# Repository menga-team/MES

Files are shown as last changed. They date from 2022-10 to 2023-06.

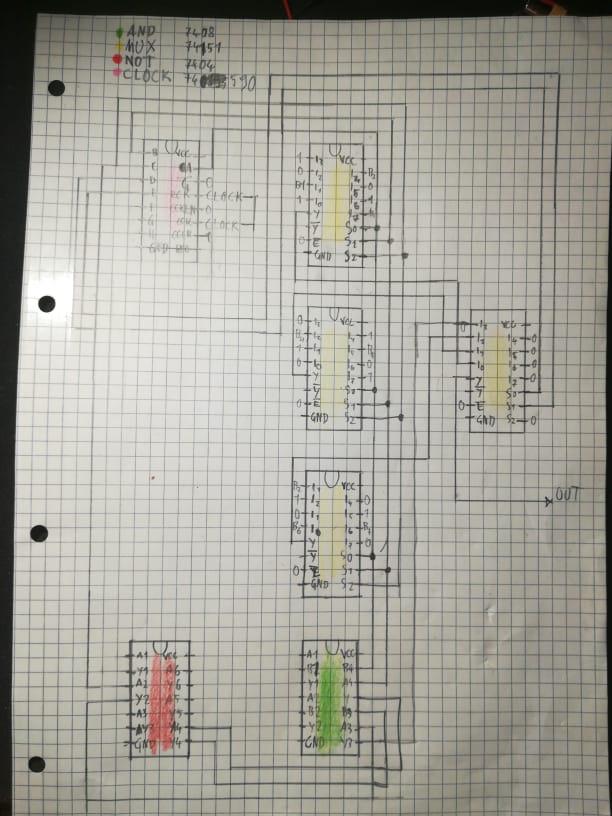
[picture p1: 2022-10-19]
controller/schematic.jpeg

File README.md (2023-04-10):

# Menga Entertainment System

MES is a cartridge-based video game console. For a tutorial and
documentation see our [wiki](https://github.com/menga-team/MES/wiki)

## Installation

### Clone the repository with submodules:

```shell
# via SSH
$ git clone --recursive git@github.com:menga-team/MES.git
# via HTTPS
$ git clone --recursive https://github.com/menga-team/MES.git
```

If you already cloned the repository you can initialize the submodules
with following command:`git submodule update --init`

### Make libopencm3

```shell
    $ cd libopencm3
    $ make
```

## Hacking

Thank you for considering to contribute to MES!
Here are some things before you can get started:

### Style

This repository contains a `.clang-format` file. Please format your
patches with this style guide in mind.

### Revisions

Every CPU firmware has a revision number which is incremented on every
change that concerns the firmware.  This revision number can be then
used in games (e.g. For checking if the game is compatible because
of a bug or API change).

Because its easy to forget incrementing it, we provide a git hook that
will do it for you.  To install it simply run:

```shell
$ cp hooks/post-commit .git/hooks/post-commit
$ chmod +x .git/hooks/post-commit
```

## License

```
MES
Copyright (c) 2022, 2023 menga-team

TinyMT
Copyright (c) 2011, 2013 Mutsuo Saito, Makoto Matsumoto,
Hiroshima University and The University of Tokyo.

udynlink
Copyright (c) 2016 Bogdan Marinescu
Copyright (c) 2022, 2023 menga-team

This program is free software; you can redistribute it and/or modify
it under the terms of the GNU General Public License as published by
the Free Software Foundation; either version 3 of the License, or
(at your option) any later version.

This program is distributed in the hope that it will be useful,
but WITHOUT ANY WARRANTY; without even the implied warranty of
MERCHANTABILITY or FITNESS FOR A PARTICULAR PURPOSE.  See the
GNU General Public License for more details.

You should have received a copy of the GNU General Public License
along with this program; if not, write to the Free Software
Foundation, Inc., 59 Temple Place, Suite 330, Boston, MA  02111-1307  USA
```

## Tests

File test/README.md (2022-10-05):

# MES Tests

To run any test, perform the following commands:
```
cd <test-name>
make clean && make flash
```

## Inbuilt-LED:
The inbuilt LED blinks. Used to test basic funcionality of controller and compilation pipeline.

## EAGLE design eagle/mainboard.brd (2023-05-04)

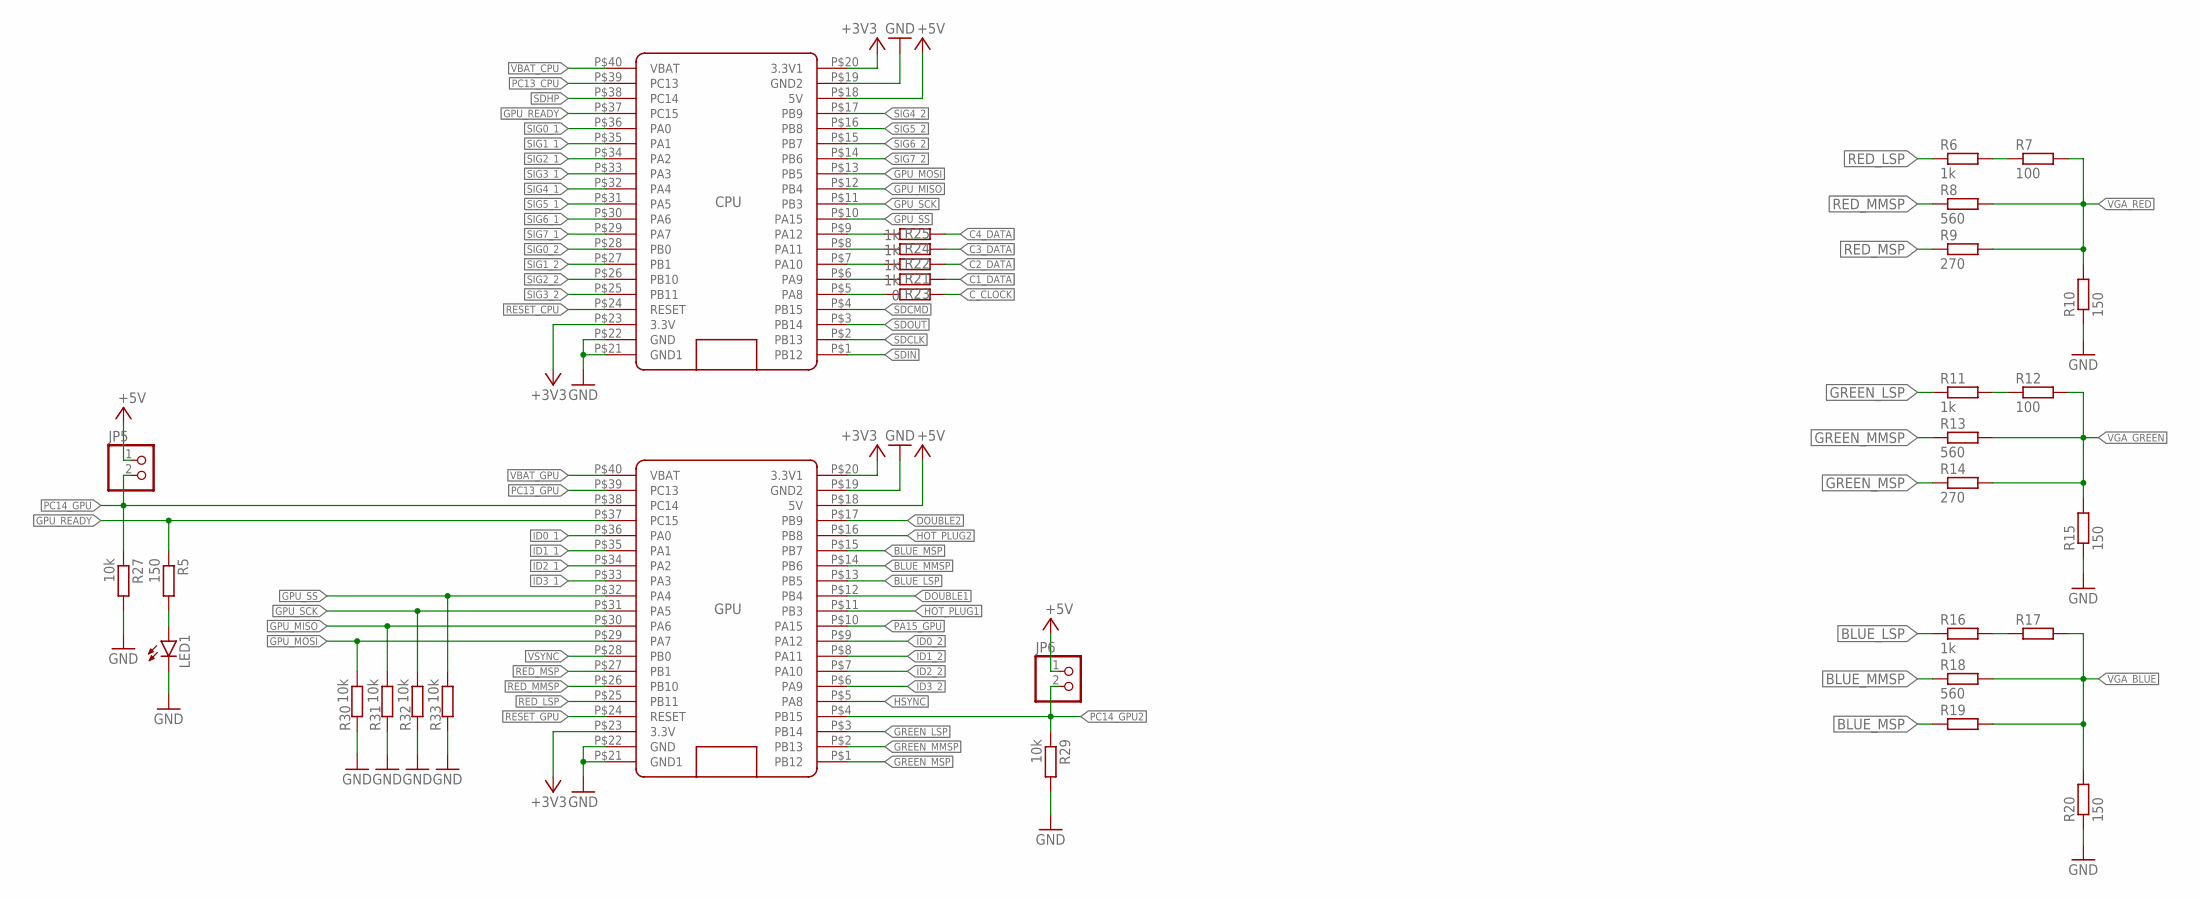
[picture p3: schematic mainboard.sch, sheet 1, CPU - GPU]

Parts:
CPU: BLUE_PILLADVANCED; BLUE_PILL_ADV
GPU: BLUE_PILLADVANCED; BLUE_PILL_ADV
JP5, JP6: PINHD-1X2; 1X02
LED1: LEDCHIPLED_0805; CHIPLED_0805
R5, R10, R15, R20: 150; R0805
R6, R11, R16, R21, R22, R24, R25: 1k; R0805
R7, R12, R17: 100; R0805
R8, R13, R18: 560; R0805
R9, R14, R19: 270; R0805
R23: 0; R0805
R27, R29, R30, R31, R32, R33: 10k; R0805

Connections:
+3V3: CPU.P$20 (3.3V1), CPU.P$23 (3.3V), GPU.P$20 (3.3V1), GPU.P$23 (3.3V); also elsewhere on the board
+5V: CPU.P$18 (5V), GPU.P$18 (5V), JP5.1, JP6.1; also elsewhere on the board
BLUE_LSP: GPU.P$13 (PB5), R16.1
BLUE_MMSP: GPU.P$14 (PB6), R18.1
BLUE_MSP: GPU.P$15 (PB7), R19.1
C1_DATA: R21.1; also elsewhere on the board
C2_DATA: R22.1; also elsewhere on the board
C3_DATA: R24.1; also elsewhere on the board
C4_DATA: R25.1; also elsewhere on the board
C_CLOCK: R23.1; also elsewhere on the board
DOUBLE1: GPU.P$12 (PB4); also elsewhere on the board
DOUBLE2: GPU.P$17 (PB9); also elsewhere on the board
GND: CPU.P$19 (GND2), CPU.P$21 (GND1), CPU.P$22 (GND), GPU.P$19 (GND2), GPU.P$21 (GND1), GPU.P$22 (GND), LED1.C, R10.1, R15.1, R20.1, R27.2, R29.2, R30.2, R31.2, R32.2, R33.2; also elsewhere on the board
GPU_MISO: CPU.P$12 (PB4), GPU.P$30 (PA6), R31.1
GPU_MOSI: CPU.P$13 (PB5), GPU.P$29 (PA7), R30.1
GPU_READY: CPU.P$37 (PC15), GPU.P$37 (PC15), R5.1
GPU_SCK: CPU.P$11 (PB3), GPU.P$31 (PA5), R32.1
GPU_SS: CPU.P$10 (PA15), GPU.P$32 (PA4), R33.1
GREEN_LSP: GPU.P$3 (PB14), R11.1
GREEN_MMSP: GPU.P$2 (PB13), R13.1
GREEN_MSP: GPU.P$1 (PB12), R14.1
HOT_PLUG1: GPU.P$11 (PB3); also elsewhere on the board
HOT_PLUG2: GPU.P$16 (PB8); also elsewhere on the board
HSYNC: GPU.P$5 (PA8); also elsewhere on the board
ID0_1: GPU.P$36 (PA0); also elsewhere on the board
ID0_2: GPU.P$9 (PA12); also elsewhere on the board
ID1_1: GPU.P$35 (PA1); also elsewhere on the board
ID1_2: GPU.P$8 (PA11); also elsewhere on the board
ID2_1: GPU.P$34 (PA2); also elsewhere on the board
ID2_2: GPU.P$7 (PA10); also elsewhere on the board
ID3_1: GPU.P$33 (PA3); also elsewhere on the board
ID3_2: GPU.P$6 (PA9); also elsewhere on the board
unnamed: LED1.A, R5.2
unnamed: R6.2, R7.1
unnamed: R11.2, R12.1
unnamed: R16.2, R17.1
PA8_CPU: CPU.P$5 (PA8), R23.2
PA9_CPU: CPU.P$6 (PA9), R21.2
PA9_CPU1: CPU.P$8 (PA11), R24.2
PA10_CPU: CPU.P$7 (PA10), R22.2
PA10_CPU1: CPU.P$9 (PA12), R25.2
PA15_GPU: GPU.P$10 (PA15)
PC13_CPU: CPU.P$39 (PC13)
PC13_GPU: GPU.P$39 (PC13)
PC14_GPU: GPU.P$38 (PC14), JP5.2, R27.1
PC14_GPU2: GPU.P$4 (PB15), JP6.2, R29.1
RED_LSP: GPU.P$25 (PB11), R6.1
RED_MMSP: GPU.P$26 (PB10), R8.1
RED_MSP: GPU.P$27 (PB1), R9.1
RESET_CPU: CPU.P$24 (RESET)
RESET_GPU: GPU.P$24 (RESET)
SDCLK: CPU.P$2 (PB13); also elsewhere on the board
SDCMD: CPU.P$4 (PB15); also elsewhere on the board
SDHP: CPU.P$38 (PC14); also elsewhere on the board
SDIN: CPU.P$1 (PB12); also elsewhere on the board
SDOUT: CPU.P$3 (PB14); also elsewhere on the board
SIG0_1: CPU.P$36 (PA0); also elsewhere on the board
SIG0_2: CPU.P$28 (PB0); also elsewhere on the board
SIG1_1: CPU.P$35 (PA1); also elsewhere on the board
SIG1_2: CPU.P$27 (PB1); also elsewhere on the board
SIG2_1: CPU.P$34 (PA2); also elsewhere on the board
SIG2_2: CPU.P$26 (PB10); also elsewhere on the board
SIG3_1: CPU.P$33 (PA3); also elsewhere on the board
SIG3_2: CPU.P$25 (PB11); also elsewhere on the board
SIG4_1: CPU.P$32 (PA4); also elsewhere on the board
SIG4_2: CPU.P$17 (PB9); also elsewhere on the board
SIG5_1: CPU.P$31 (PA5); also elsewhere on the board
SIG5_2: CPU.P$16 (PB8); also elsewhere on the board
SIG6_1: CPU.P$30 (PA6); also elsewhere on the board
SIG6_2: CPU.P$15 (PB7); also elsewhere on the board
SIG7_1: CPU.P$29 (PA7); also elsewhere on the board
SIG7_2: CPU.P$14 (PB6); also elsewhere on the board
VBAT_CPU: CPU.P$40 (VBAT)
VBAT_GPU: GPU.P$40 (VBAT)
VGA_BLUE: R17.2, R18.2, R19.2, R20.2; also elsewhere on the board
VGA_GREEN: R12.2, R13.2, R14.2, R15.2; also elsewhere on the board
VGA_RED: R7.2, R8.2, R9.2, R10.2; also elsewhere on the board
VSYNC: GPU.P$28 (PB0); also elsewhere on the board

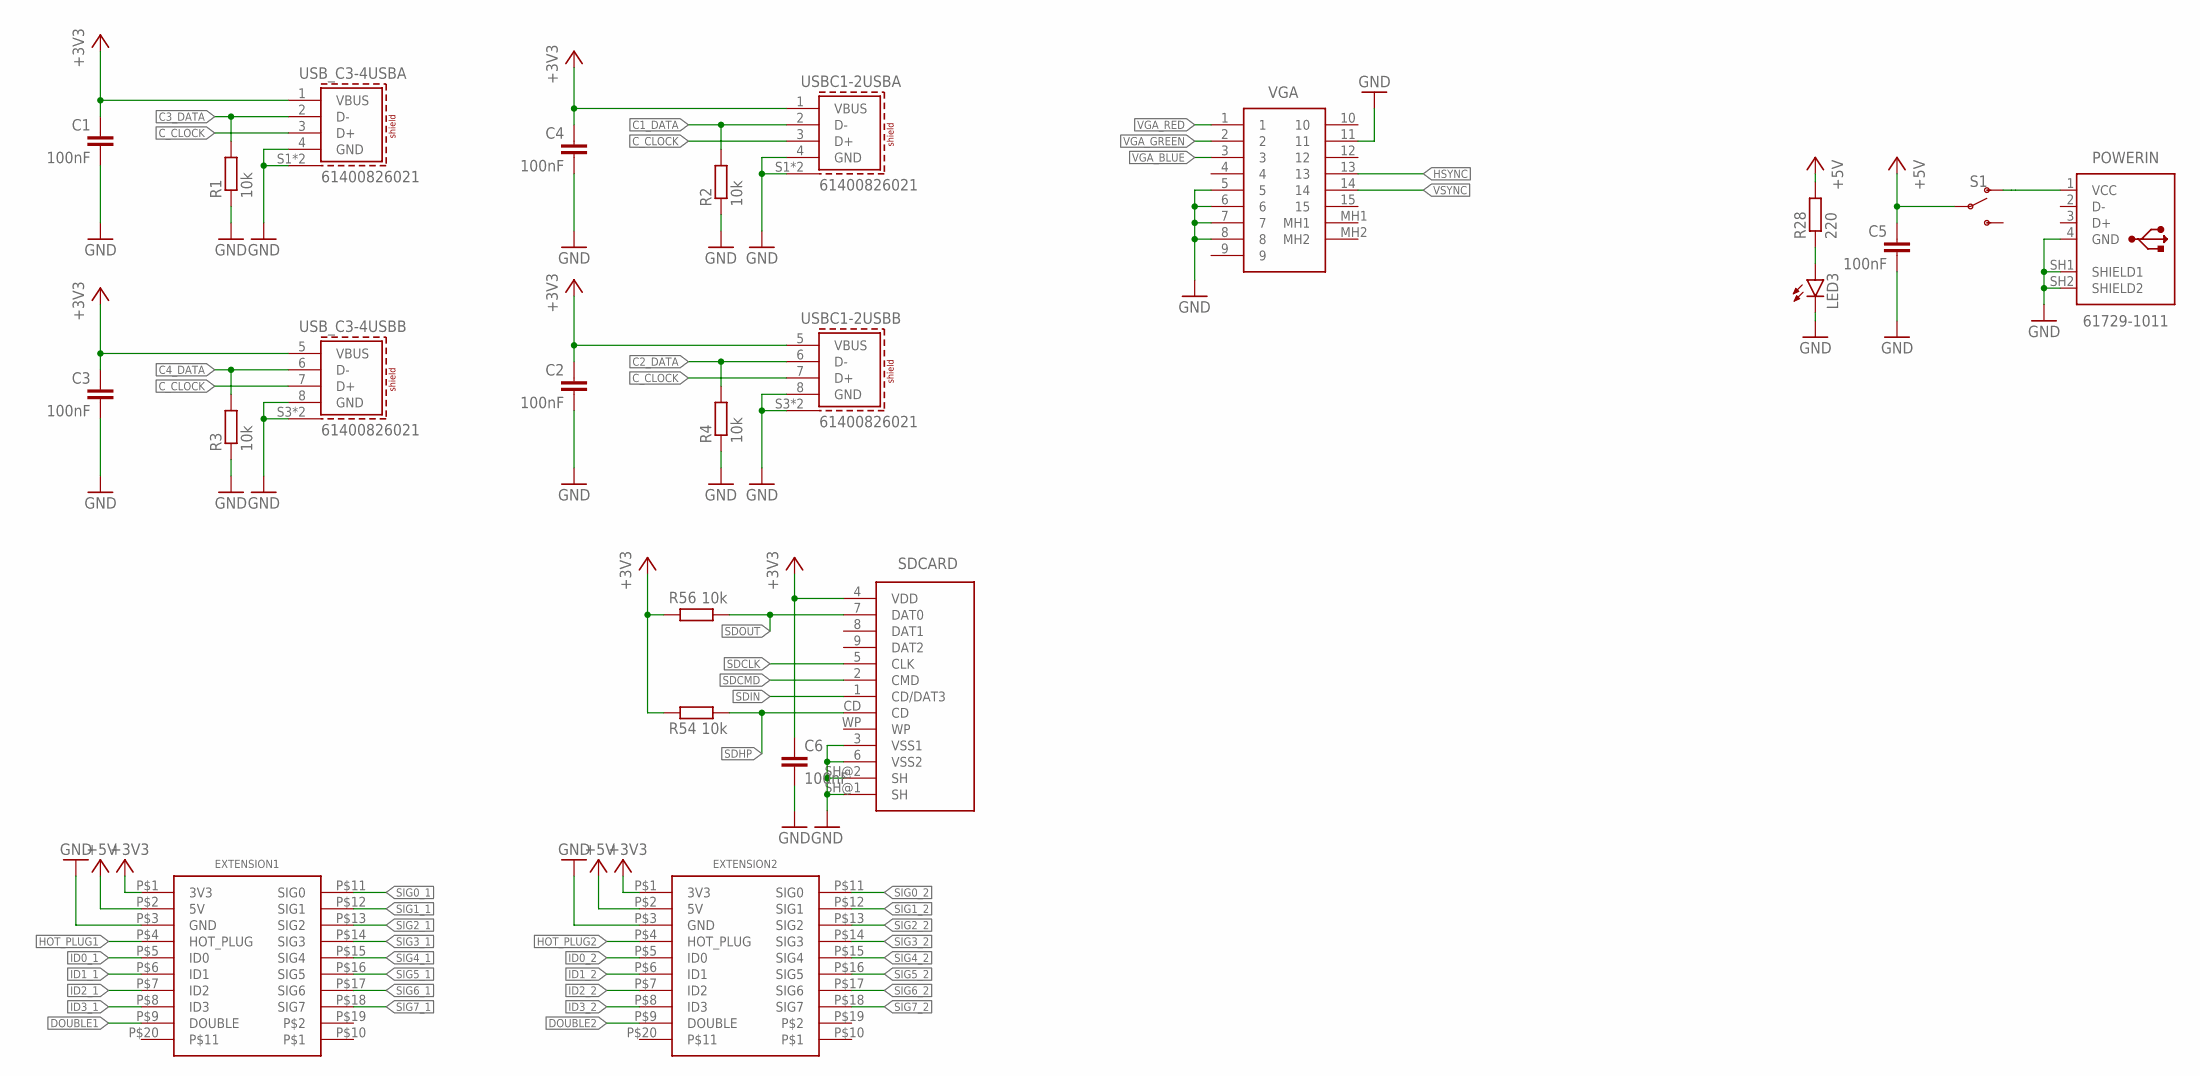
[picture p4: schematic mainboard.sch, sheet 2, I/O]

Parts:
C1, C2, C3, C4, C5, C6: 100nF; C0805
EXTENSION1, EXTENSION2: 3511220BMSS0BNA1_2.54MM_2X20_MALE
LED3: LEDCHIPLED_0805; CHIPLED_0805
POWERIN: 61729-1011; 61729-1011BLF
R1, R2, R3, R4, R54, R56: 10k; R0805
R28: 220; R0805
S1: SWITCH-SPDT-PTH-11.6X4.0MM; SWITCH_SPDT_PTH_11.6X4.0MM
SD-CARD: SD_CARD_SOCKET; SD
USBC1-2: 61400826021
USB_C3-4: 61400826021
VGA: L77HDE15SD1CH4RHNVGA

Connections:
+3V3: C1.1, C2.1, C3.1, C4.1, C6.1, EXTENSION1.P$1 (3V3), EXTENSION2.P$1 (3V3), R54.2, R56.2, SD-CARD.4 (VDD), USBC1-2.1 (VBUS), USBC1-2.5 (VBUS), USB_C3-4.1 (VBUS), USB_C3-4.5 (VBUS); also elsewhere on the board
+5V: C5.1, EXTENSION1.P$2 (5V), EXTENSION2.P$2 (5V), R28.2, S1.2; also elsewhere on the board
C1_DATA: R2.2, USBC1-2.2 (D-); also elsewhere on the board
C2_DATA: R4.2, USBC1-2.6 (D-); also elsewhere on the board
C3_DATA: R1.2, USB_C3-4.2 (D-); also elsewhere on the board
C4_DATA: R3.2, USB_C3-4.6 (D-); also elsewhere on the board
C_CLOCK: USBC1-2.3 (D+), USBC1-2.7 (D+), USB_C3-4.3 (D+), USB_C3-4.7 (D+); also elsewhere on the board
DOUBLE1: EXTENSION1.P$9 (DOUBLE); also elsewhere on the board
DOUBLE2: EXTENSION2.P$9 (DOUBLE); also elsewhere on the board
GND: C1.2, C2.2, C3.2, C4.2, C5.2, C6.2, EXTENSION1.P$3 (GND), EXTENSION2.P$3 (GND), LED3.C, POWERIN.4 (GND), POWERIN.SH1 (SHIELD1), POWERIN.SH2 (SHIELD2), R1.1, R2.1, R3.1, R4.1, SD-CARD.3 (VSS1), SD-CARD.6 (VSS2), SD-CARD.SH@1 (SH), SD-CARD.SH@2 (SH), USBC1-2.4 (GND), USBC1-2.8 (GND), USBC1-2.S1 (SHIELD), USBC1-2.S2 (SHIELD), USBC1-2.S3 (SHIELD), USBC1-2.S4 (SHIELD), USB_C3-4.4 (GND), USB_C3-4.8 (GND), USB_C3-4.S1 (SHIELD), USB_C3-4.S2 (SHIELD), USB_C3-4.S3 (SHIELD), USB_C3-4.S4 (SHIELD), VGA.5, VGA.6, VGA.7, VGA.8, VGA.11; also elsewhere on the board
HOT_PLUG1: EXTENSION1.P$4 (HOT_PLUG); also elsewhere on the board
HOT_PLUG2: EXTENSION2.P$4 (HOT_PLUG); also elsewhere on the board
HSYNC: VGA.13; also elsewhere on the board
ID0_1: EXTENSION1.P$5 (ID0); also elsewhere on the board
ID0_2: EXTENSION2.P$5 (ID0); also elsewhere on the board
ID1_1: EXTENSION1.P$6 (ID1); also elsewhere on the board
ID1_2: EXTENSION2.P$6 (ID1); also elsewhere on the board
ID2_1: EXTENSION1.P$7 (ID2); also elsewhere on the board
ID2_2: EXTENSION2.P$7 (ID2); also elsewhere on the board
ID3_1: EXTENSION1.P$8 (ID3); also elsewhere on the board
ID3_2: EXTENSION2.P$8 (ID3); also elsewhere on the board
unnamed: POWERIN.1 (VCC), S1.1 (O)
unnamed: LED3.A, R28.1
SDCLK: SD-CARD.5 (CLK); also elsewhere on the board
SDCMD: SD-CARD.2 (CMD); also elsewhere on the board
SDHP: R54.1, SD-CARD.CD; also elsewhere on the board
SDIN: SD-CARD.1 (CD/DAT3); also elsewhere on the board
SDOUT: R56.1, SD-CARD.7 (DAT0); also elsewhere on the board
SIG0_1: EXTENSION1.P$11 (SIG0); also elsewhere on the board
SIG0_2: EXTENSION2.P$11 (SIG0); also elsewhere on the board
SIG1_1: EXTENSION1.P$12 (SIG1); also elsewhere on the board
SIG1_2: EXTENSION2.P$12 (SIG1); also elsewhere on the board
SIG2_1: EXTENSION1.P$13 (SIG2); also elsewhere on the board
SIG2_2: EXTENSION2.P$13 (SIG2); also elsewhere on the board
SIG3_1: EXTENSION1.P$14 (SIG3); also elsewhere on the board
SIG3_2: EXTENSION2.P$14 (SIG3); also elsewhere on the board
SIG4_1: EXTENSION1.P$15 (SIG4); also elsewhere on the board
SIG4_2: EXTENSION2.P$15 (SIG4); also elsewhere on the board
SIG5_1: EXTENSION1.P$16 (SIG5); also elsewhere on the board
SIG5_2: EXTENSION2.P$16 (SIG5); also elsewhere on the board
SIG6_1: EXTENSION1.P$17 (SIG6); also elsewhere on the board
SIG6_2: EXTENSION2.P$17 (SIG6); also elsewhere on the board
SIG7_1: EXTENSION1.P$18 (SIG7); also elsewhere on the board
SIG7_2: EXTENSION2.P$18 (SIG7); also elsewhere on the board
VGA_BLUE: VGA.3; also elsewhere on the board
VGA_GREEN: VGA.2; also elsewhere on the board
VGA_RED: VGA.1; also elsewhere on the board
VSYNC: VGA.14; also elsewhere on the board

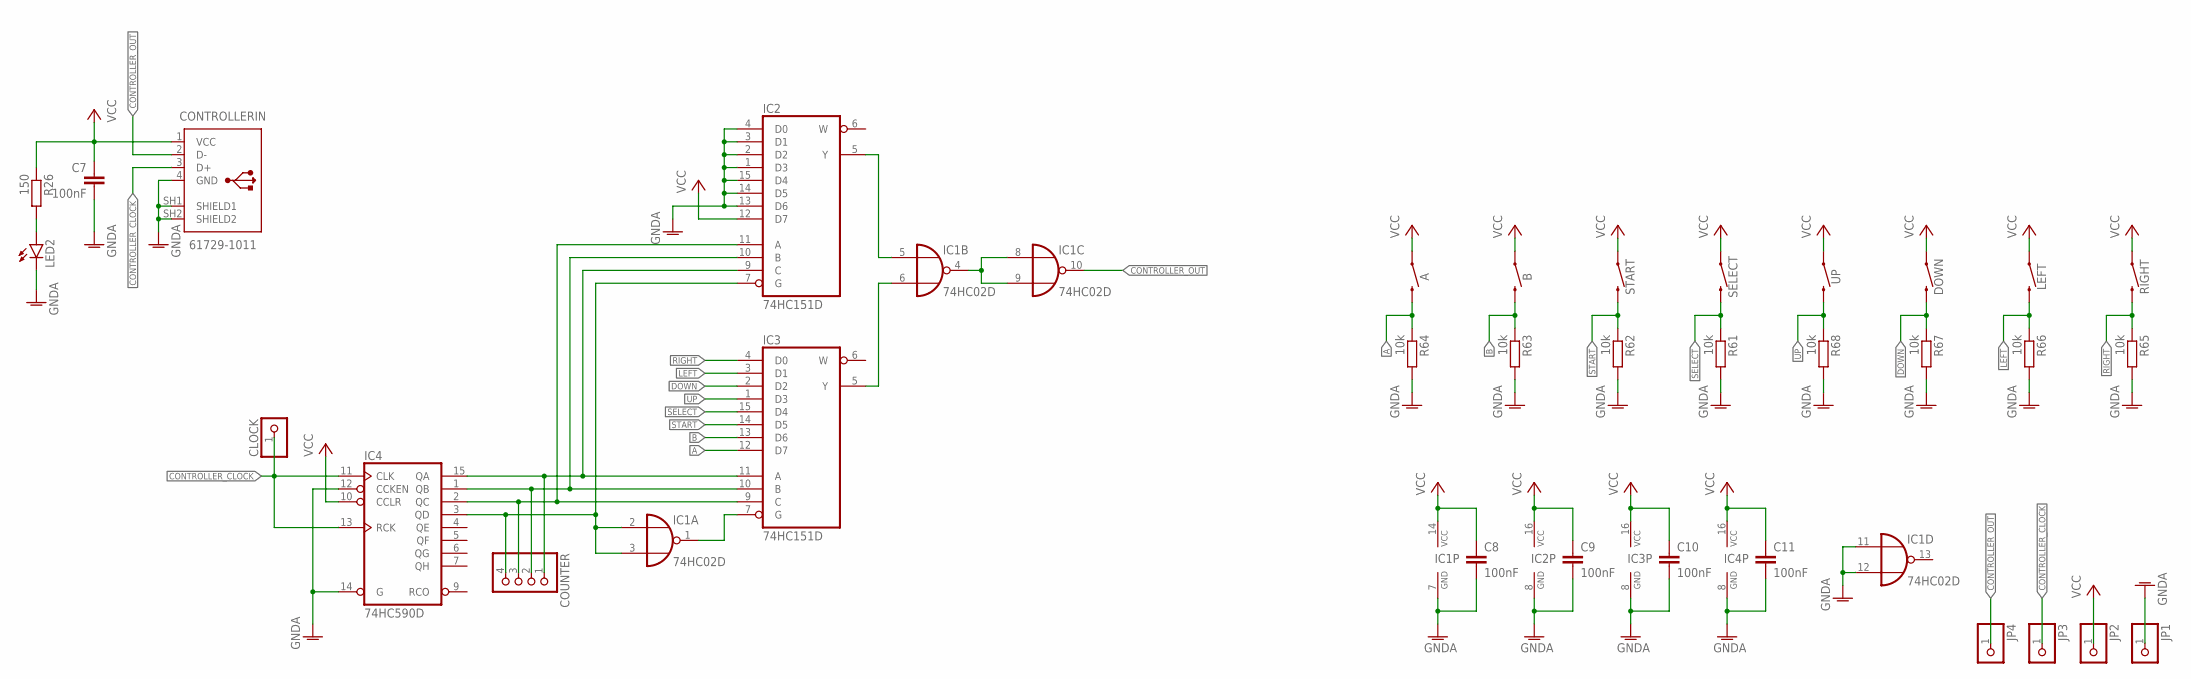
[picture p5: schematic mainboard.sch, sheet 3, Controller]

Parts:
A: MOMENTARY-SWITCH-SPST-PTH-12MM; TACTILE_SWITCH_PTH_12MM
B: MOMENTARY-SWITCH-SPST-PTH-12MM; TACTILE_SWITCH_PTH_12MM
C7, C8, C9, C10, C11: 100nF; C0805
CLOCK: PINHD-1X1; 1X01
CONTROLLERIN: 61729-1011; 61729-1011BLF
COUNTER: PINHD-1X4; 1X04
DOWN: MOMENTARY-SWITCH-SPST-PTH-12MM; TACTILE_SWITCH_PTH_12MM
IC1: 74HC02D; SO14
IC2, IC3: 74HC151D; SO16
IC4: 74HC590D; SO16
JP1, JP2, JP3, JP4: PINHD-1X1; 1X01
LED2: LEDCHIPLED_0805; CHIPLED_0805
LEFT: MOMENTARY-SWITCH-SPST-PTH-12MM; TACTILE_SWITCH_PTH_12MM
R26: 150; R0805
R61, R62, R63, R64, R65, R66, R67, R68: 10k; R0805
RIGHT: MOMENTARY-SWITCH-SPST-PTH-12MM; TACTILE_SWITCH_PTH_12MM
SELECT: MOMENTARY-SWITCH-SPST-PTH-12MM; TACTILE_SWITCH_PTH_12MM
START: MOMENTARY-SWITCH-SPST-PTH-12MM; TACTILE_SWITCH_PTH_12MM
UP: MOMENTARY-SWITCH-SPST-PTH-12MM; TACTILE_SWITCH_PTH_12MM

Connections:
A: A.3 (2), IC3.12 (D7), R64.1
B: B.3 (2), IC3.13 (D6), R63.1
CONTROLLER_CLOCK: CLOCK.1, CONTROLLERIN.3 (D+), IC4.11 (CLK), IC4.13 (RCK), JP3.1
CONTROLLER_OUT: CONTROLLERIN.2 (D-), IC1.10 (O), JP4.1
DOWN: DOWN.3 (2), IC3.2 (D2), R67.1
GNDA: C7.2, C8.2, C9.2, C10.2, C11.2, CONTROLLERIN.4 (GND), CONTROLLERIN.SH1 (SHIELD1), CONTROLLERIN.SH2 (SHIELD2), IC1.7 (GND), IC1.11 (I0), IC1.12 (I1), IC2.1 (D3), IC2.2 (D2), IC2.3 (D1), IC2.4 (D0), IC2.8 (GND), IC2.13 (D6), IC2.14 (D5), IC2.15 (D4), IC3.8 (GND), IC4.8 (GND), IC4.12 (CCKEN), IC4.14 (G), JP1.1, LED2.C, R61.2, R62.2, R63.2, R64.2, R65.2, R66.2, R67.2, R68.2
LEFT: IC3.3 (D1), LEFT.3 (2), R66.1
unnamed: LED2.A, R26.2
unnamed: IC1.5 (I0), IC2.5 (Y)
unnamed: IC1.6 (I1), IC3.5 (Y)
unnamed: IC1.4 (O), IC1.8 (I0), IC1.9 (I1)
unnamed: COUNTER.1, IC2.9 (C), IC3.11 (A), IC4.15 (QA)
unnamed: COUNTER.2, IC2.10 (B), IC3.10 (B), IC4.1 (QB)
unnamed: COUNTER.3, IC2.11 (A), IC3.9 (C), IC4.2 (QC)
unnamed: COUNTER.4, IC1.2 (I0), IC1.3 (I1), IC2.7 (G), IC4.3 (QD)
unnamed: IC1.1 (O), IC3.7 (G)
RIGHT: IC3.4 (D0), R65.1, RIGHT.3 (2)
SELECT: IC3.15 (D4), R61.1, SELECT.3 (2)
START: IC3.14 (D5), R62.1, START.3 (2)
UP: IC3.1 (D3), R68.1, UP.3 (2)
VCC: A.1, B.1, C7.1, C8.1, C9.1, C10.1, C11.1, CONTROLLERIN.1 (VCC), DOWN.1, IC1.14 (VCC), IC2.12 (D7), IC2.16 (VCC), IC3.16 (VCC), IC4.10 (CCLR), IC4.16 (VCC), JP2.1, LEFT.1, R26.1, RIGHT.1, SELECT.1, START.1, UP.1

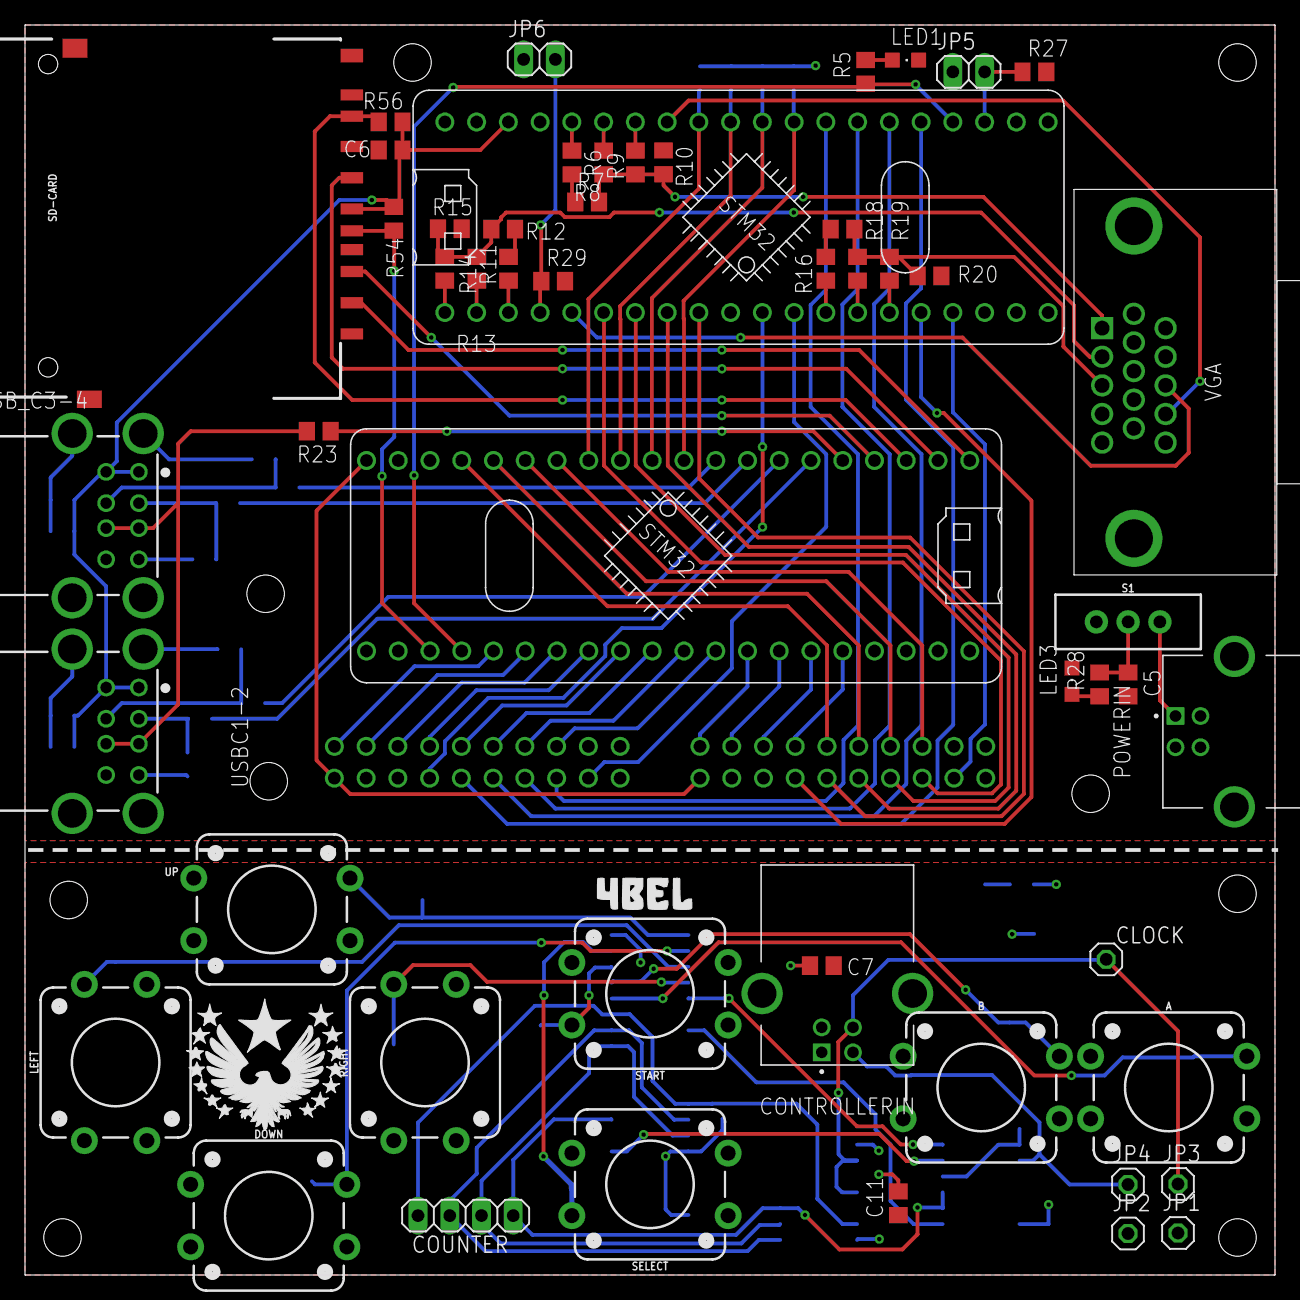
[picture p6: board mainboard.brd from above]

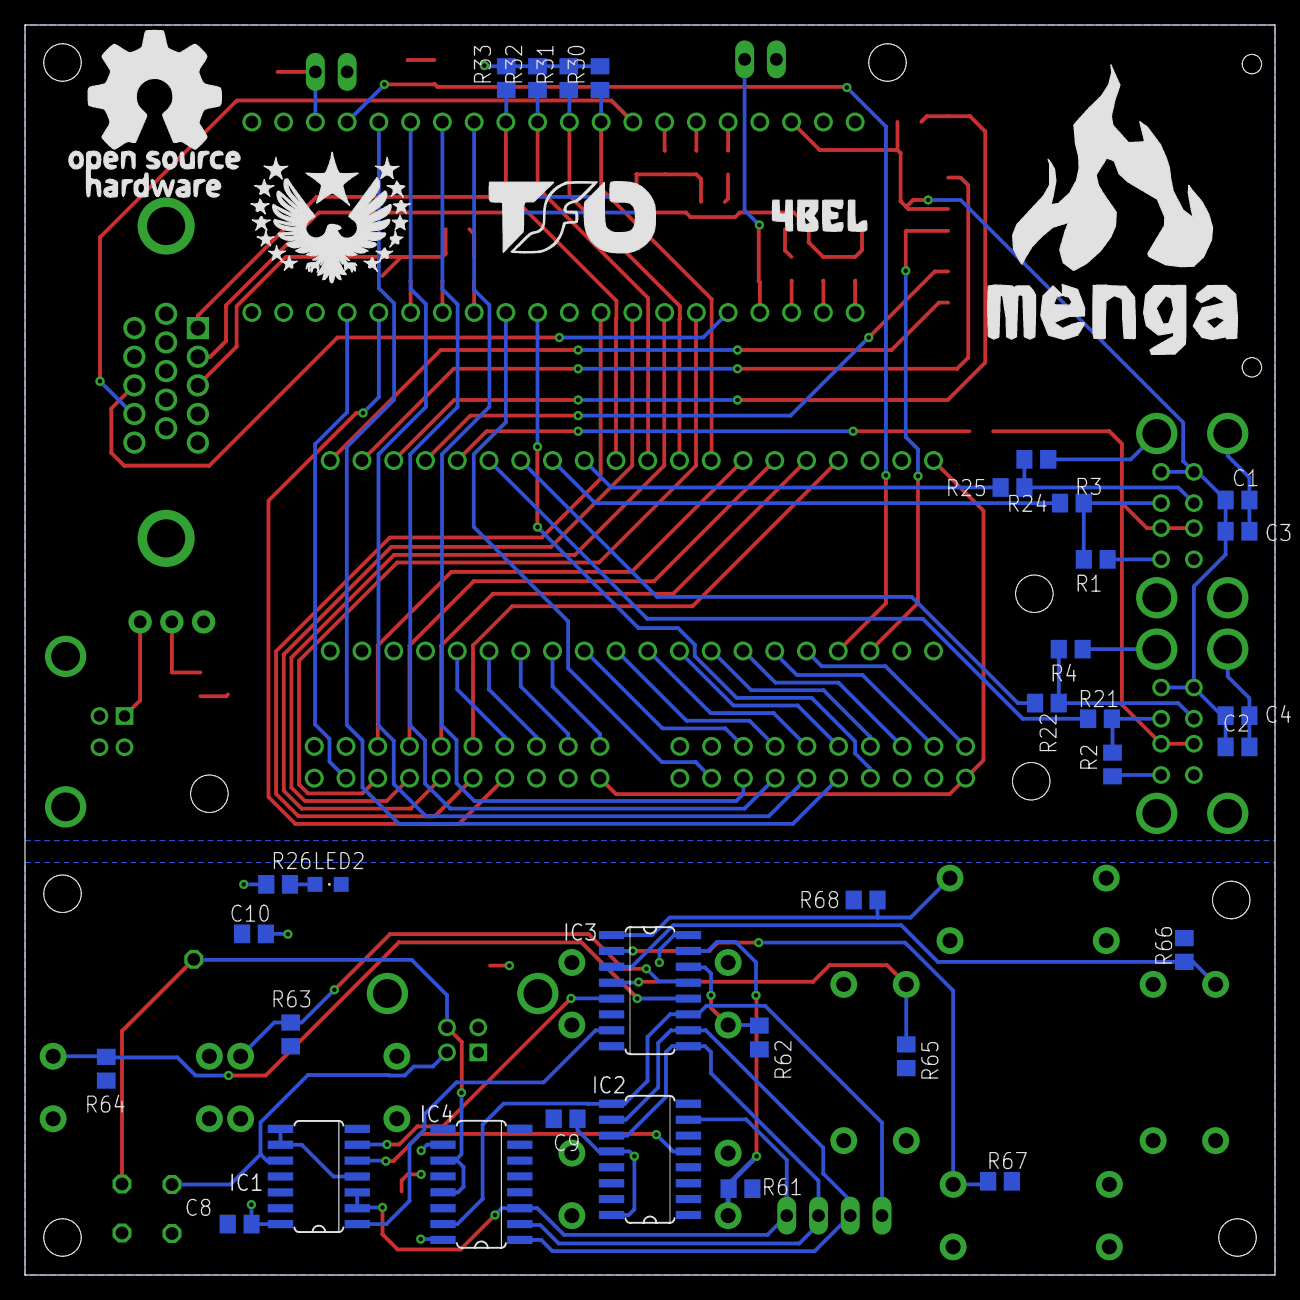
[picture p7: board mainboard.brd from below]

Board: 2 copper layers, 100.0 x 100.0 mm, 88 parts (33 on the bottom side), 94 nets.

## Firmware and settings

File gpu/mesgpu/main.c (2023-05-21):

#include "main.h"
#include "gpu.h"
#include "libopencm3/cm3/systick.h"
#include "mesgraphics.h"
#include <libopencm3/cm3/nvic.h>
#include <libopencm3/stm32/dma.h>
#include <libopencm3/stm32/gpio.h>
#include <libopencm3/stm32/rcc.h>
#include <libopencm3/stm32/spi.h>
#include <libopencm3/stm32/timer.h>
#include <memory.h>
#include <mesmath.h>
#include <stdint.h>
#include <stdio.h>

// Include error screen as 'error'
#include "images/error.m3ifc"
// Include cpu timeout screen as 'cpu_timeout'
#include "images/cpu_timeout.m3ifc"
// The boot screen
#include "images/splash_screen.m3ifc"
// The adjust brightness screen
#include "images/adjust_brightness.m3ifc"
// Sdcard icon
#include "images/sdcard.m3ifc"
// Controller icons
#include "images/controller1.m3ifc"
#include "images/controller2.m3ifc"
#include "images/controller3.m3ifc"
#include "images/controller4.m3ifc"

int main(void) {
    rcc_clock_setup_pll(&rcc_hse_configs[RCC_CLOCK_HSE8_72MHZ]);
    setup_output();
    gpu_init();
    setup_video();
    start_communication();
    start_video();
    // Setup timeout
    systick_clear();
    systick_set_clocksource(STK_CSR_CLKSOURCE_AHB_DIV8);
    systick_set_reload(16777215); // 24-bit limit. (~1.8s)
    systick_interrupt_enable();
    systick_counter_enable();
    while (run) {
        // we have ~5µs every line and ~770µs every frame
        handle_operation();
    }

    while (true)
        ;
}

void sys_tick_handler(void) {
    systick_interrupt_disable();
    systick_counter_disable();
    systick_clear();
    // Did we sync after ~1.8s?
    // If we didn't then show the timeout error.
    if (processing_stage == UNINITIALIZED) {
        // Show timeout screen if cpu failed to sync.
        cpu_communication_timeout();
        // Run gets disabled when the 1. operation sent is not the init
        // operation. Inorder to help debugging we will display the
        // "COM_BRK" error, meaning the gpu is able to recieve from the
        // cpu, but the communication might be unreliable.
        if (!run) {
            gpu_write(front_buffer, 118, 112, 2, 3, "COM_BRK");
        }
    }
}

void setup_output(void) {
    rcc_periph_clock_enable(RCC_AFIO);
    rcc_periph_clock_enable(RCC_GPIOA);
    rcc_periph_clock_enable(RCC_GPIOB);
    rcc_periph_clock_enable(RCC_GPIOC);
    gpio_set_mode(GPIOC, GPIO_MODE_OUTPUT_2_MHZ, GPIO_CNF_OUTPUT_PUSHPULL,
                  GPIO13); // built-in
    gpio_set_mode(GPU_READY_PORT, GPIO_MODE_OUTPUT_2_MHZ,
                  GPIO_CNF_OUTPUT_PUSHPULL, GPU_READY);
    gpio_clear(GPU_READY_PORT, GPU_READY); // set gpu ready to low
    gpio_set(GPIOC, GPIO13);
    // A8: hsync (yellow cable)
    // B0: vsync (orange cable)
    gpio_set_mode(GPIOA, GPIO_MODE_OUTPUT_2_MHZ, GPIO_CNF_OUTPUT_ALTFN_PUSHPULL,
                  GPIO_TIM1_CH1); // PA8
    gpio_set_mode(GPIOB, GPIO_MODE_OUTPUT_2_MHZ, GPIO_CNF_OUTPUT_ALTFN_PUSHPULL,
                  GPIO_TIM3_CH3); // PB0
    gpio_set_mode(GPIO_COLOR_PORT, GPIO_MODE_OUTPUT_50_MHZ,
                  GPIO_CNF_OUTPUT_PUSHPULL,
                  RED_MSP | RED_MMSP | RED_LSP | GREEN_MSP | GREEN_MMSP |
                      GREEN_LSP | BLUE_MSP | BLUE_MMSP | BLUE_LSP);
    gpio_clear(GPIO_COLOR_PORT, GPIO_ALL); // reset colors
}

void setup_video(void) { gpu_blank(front_buffer, 0x00); }

void start_communication(void) {
    RCC_APB1ENR &= ~RCC_APB1ENR_I2C1EN; // disable i2c if it happend to be
                                        // enabled, see erata.
    // SS=PA4 SCK=PA5 MISO=PA6 MOSI=PA7
    gpio_set_mode(GPIOA, GPIO_MODE_OUTPUT_50_MHZ,
                  GPIO_CNF_OUTPUT_ALTFN_PUSHPULL, GPIO6);
    gpio_set_mode(GPIOA, GPIO_MODE_INPUT, GPIO_CNF_INPUT_FLOAT,
                  GPIO5 | GPIO4 | GPIO7);
    rcc_periph_clock_enable(RCC_SPI1);
    spi_reset(SPI1);
    spi_set_slave_mode(SPI1);
    spi_set_clock_polarity_0(SPI1);
    spi_set_clock_phase_1(SPI1);
    spi_set_dff_8bit(SPI1);
    spi_send_msb_first(SPI1);
    spi_enable(SPI1);
    rcc_periph_clock_enable(RCC_DMA1);
    nvic_set_priority(NVIC_DMA1_CHANNEL2_IRQ, 1);
    nvic_enable_irq(NVIC_DMA1_CHANNEL2_IRQ);
    dma_channel_reset(DMA1, DMA_CHANNEL2);
    dma_set_peripheral_address(DMA1, DMA_CHANNEL2, (uint32_t)&SPI1_DR);
    dma_set_read_from_peripheral(DMA1, DMA_CHANNEL2);
    dma_enable_memory_increment_mode(DMA1, DMA_CHANNEL2);
    dma_set_peripheral_size(DMA1, DMA_CHANNEL2, DMA_CCR_PSIZE_8BIT);
    dma_set_memory_size(DMA1, DMA_CHANNEL2, DMA_CCR_MSIZE_8BIT);
    dma_set_priority(DMA1, DMA_CHANNEL2, DMA_CCR_PL_VERY_HIGH);
    dma_enable_transfer_complete_interrupt(DMA1, DMA_CHANNEL2);
    spi_enable_rx_dma(SPI1);
    dma_recieve_operation();
    gpu_ready_port = 0;
}

void dma_recieve_operation(void) {
    dma_recieve((uint32_t)&operation, OPERATION_LENGTH);
}

void dma_recieve(uint32_t adr, uint32_t len) {
    dma_set_memory_address(DMA1, DMA_CHANNEL2, adr);
    dma_set_number_of_data(DMA1, DMA_CHANNEL2, len);
    dma_enable_channel(DMA1, DMA_CHANNEL2);
}

void start_video(void) {
    // timers are driven by a 72MHz clock
    // TIM1 -> H-SYNC & scanline interrupt
    rcc_periph_clock_enable(RCC_TIM1);
    rcc_periph_reset_pulse(RST_TIM1);
    timer_enable_break_main_output(TIM1);
    timer_set_mode(TIM1, TIM_CR1_CKD_CK_INT, TIM_CR1_CMS_EDGE, TIM_CR1_DIR_UP);
    // 25175000/4 = 6293750
    // 72000000/6293750 = 11.44 = 11
    timer_set_prescaler(TIM1,
                        uround((double)rcc_apb2_frequency /
                               (double)(PIXEL_CLOCK / BUFFER_TO_VIDEO_RATIO)) -
                            1);
    timer_set_period(TIM1, (H_WHOLE_LINE_PIXELS / BUFFER_TO_VIDEO_RATIO) - 1);
    timer_disable_preload(TIM1);
    timer_continuous_mode(TIM1);
    timer_set_counter(TIM1, 0);
    timer_enable_oc_preload(TIM1, TIM_OC1);
    timer_enable_oc_output(TIM1, TIM_OC1);
    timer_set_oc_mode(TIM1, TIM_OC1, TIM_OCM_PWM1);
    // This OC is responsible for the horizontal sync pulse...
    // We will send the sync pulse at the beging because it is easier.
    // The backporch will follow after it, and the front porch is at the
    // end.
    timer_set_oc_value(TIM1, TIM_OC1,
                       (H_SYNC_PULSE_PIXELS / BUFFER_TO_VIDEO_RATIO) - 1);
#if H_SYNC_POLARITY == 1
    timer_set_oc_polarity_high(TIM1, TIM_OC1);
#else
    timer_set_oc_polarity_low(TIM1, TIM_OC1);
#endif
    nvic_enable_irq(NVIC_TIM1_CC_IRQ);
    nvic_set_priority(NVIC_TIM1_CC_IRQ, 0);
    // OC2 will let us know when we need to start preparing and outputting
    // the image Start a little sooner because we are doing more than just
    // outputting the pixels.
    timer_set_oc_value(
        TIM1, TIM_OC2,
        ((H_SYNC_PULSE_PIXELS + H_BACK_PORCH_PIXELS) / BUFFER_TO_VIDEO_RATIO) -
            9);
    timer_enable_irq(TIM1, TIM_DIER_CC2IE);
    // TIM3 -> V-SYNC & line count
    rcc_periph_clock_enable(RCC_TIM3);
    rcc_periph_reset_pulse(RST_TIM3);
    timer_set_mode(TIM3, TIM_CR1_CKD_CK_INT, TIM_CR1_CMS_EDGE, TIM_CR1_DIR_UP);
    // 25175000/4 = 6293750
    // 6293750/200 = 31468.75
    // 72000000.0/31468.75 = 228.8 = 229
    timer_set_prescaler(
        TIM3, uround((double)rcc_apb2_frequency /
                     (double)((double)(PIXEL_CLOCK / BUFFER_TO_VIDEO_RATIO) /
                              (double)(H_WHOLE_LINE_PIXELS /
                                       BUFFER_TO_VIDEO_RATIO))) -
                  1);
    timer_set_period(TIM3, V_WHOLE_FRAME_LINES - 1);
    timer_disable_preload(TIM3);
    timer_continuous_mode(TIM3);
    timer_set_oc_value(TIM3, TIM_OC3, V_SYNC_PULSE_LINES);
    timer_set_counter(TIM3, 0);
    timer_enable_oc_preload(TIM3, TIM_OC3);
    timer_enable_oc_output(TIM3, TIM_OC3);
    timer_set_oc_mode(TIM3, TIM_OC3, TIM_OCM_PWM1);
#if V_SYNC_POLARITY == 1
    timer_set_oc_polarity_high(TIM3, TIM_OC3);
#else
    timer_set_oc_polarity_low(TIM3, TIM_OC3);
#endif
    // initialize line counters
    buffer_line = 0;
    sub_line = -1;
    // start timers
    timer_enable_counter(TIM3);
    timer_enable_counter(TIM1);
}

void __attribute__((optimize("O3"))) tim1_cc_isr(void) {
    TIM_SR(TIM1) = 0x0000;
    if (TIM3_CNT > V_SYNC_PULSE_LINES + V_BACK_PORCH_LINES - 3 &&
        TIM3_CNT <
            V_SYNC_PULSE_LINES + V_BACK_PORCH_LINES + V_DISPLAY_LINES - 20) {
        // while drawing we don't want to communicate, because DMA and
        // CPU can only access memory one at a time. When we are
        // recieving data and drawing at the same time, artifacts will
        // appear.
        GPIO_BRR(GPU_READY_PORT) = GPU_READY;

        // Increment subline
        sub_line++;

        // Send the scanline
        line = (const void *)front_buffer +
               (buffer_line * (BUFFER_WIDTH / 8) * BUFFER_BPP);

#include "scanline.g.c"

        // Some monitors sample their black voltage level in the back
        // porch, so we need to stop outputting color.
        GPIO_BRR(GPIO_COLOR_PORT) = GPIO_ALL;

        // Branches are last because we don't want variable execution
        // time before sending the pixels.
        if (sub_line == BUFFER_TO_VIDEO_RATIO) {
            buffer_line++;
            sub_line = 0;
        }
        if (buffer_line == BUFFER_HEIGHT)
            buffer_line = 0;
    } else {
        // we don't want to send a possible GPU_READY after finishing a
        // line, because that's just to many interrupts.
        GPIO_ODR(GPU_READY_PORT) = gpu_ready_port;
    }
}

void generic_error(void) {
    run = false;
    gpu_ready_port = 0;
    color_palette[0] = COLOR(0b000, 0b000, 0b111);
    color_palette[1] = COLOR(0b111, 0b111, 0b111);
    memcpy(front_buffer, error, SCREEN_BUFFER_SIZE);
}

void invalid_operation(uint8_t *invalid_op) {
    generic_error();
    gpu_write(front_buffer, 2, 80, 1, 0, "-UNIMPLEMENTED  OPERATION-");
    char *operation_string = malloc(sizeof(char) * 25); // 24chars + NUL
    sprintf(operation_string, "%02x %02x %02x %02x  %02x %02x %02x %02x",
            invalid_op[0], invalid_op[1], invalid_op[2], invalid_op[3],
            invalid_op[4], invalid_op[5], invalid_op[6], invalid_op[7]);
    gpu_write(front_buffer, 8, 96, 1, 0, operation_string);
    free(operation_string);
}

void unexpected_data(enum Stage c_stage) {
    generic_error();
    gpu_write(front_buffer, 2, 80, 1, 0, "  -  UNEXPECTED  DATA  -  ");
    gpu_write(front_buffer, 0, 88, 1, 0, "Current processing stage:");
    char *buf = malloc(sizeof(char) * 27); // 26chars (whole line) + NUL
    sprintf(buf, "%s (%02x)", stage_pretty_names[c_stage], c_stage);
    gpu_write(front_buffer, 0, 96, 1, 0, buf);
    sprintf(buf, "Recieved data: (%04lx)", DMA_CMAR(DMA1, DMA_CHANNEL2));
    gpu_write(front_buffer, 0, 104, 1, 0, buf);
    uint8_t *data = (uint8_t *)DMA_CMAR(DMA1, DMA_CHANNEL2);
    sprintf(buf, "%02x%02x%02x%02x%02x%02x%02x%02x%02x%02x%02x ...", data[0],
            data[1], data[2], data[3], data[4], data[5], data[6], data[7],
            data[8], data[9], data[10]);
    gpu_write(front_buffer, 0, 112, 1, 0, buf);
    free(buf);
}

void too_large_data(uint16_t bytes) {
    generic_error();
    gpu_write(front_buffer, 2, 80, 1, 0, "-OPERATION DATA TOO LARGE-");
    char *buf = malloc(sizeof(char) * 27); // 26chars (whole line) + NUL
    sprintf(buf, "%u > %u!", bytes, OPERATION_DATA_LENGTH);
    gpu_write(front_buffer, 2, 88, 1, 0, buf);
    gpu_write(front_buffer, 2, 96, 1, 0, "OPERATION:");
    sprintf(buf, "%02x %02x %02x %02x  %02x %02x %02x %02x", operation[0],
            operation[1], operation[2], operation[3], operation[4],
            operation[5], operation[6], operation[7]);
    gpu_write(front_buffer, 2, 104, 1, 0, buf);
    free(buf);
}

void cpu_communication_timeout(void) {
    // FIXME: When a timeout is displayed the lines are in the wrong order.
    //      This is probably because the pixels get copied in a interrupt.
    //      A solution could be to copy the pixels via DMA or to copy the
    //      pixels outside of the interrupt.
    color_palette[0] = COLOR(0b000, 0b000, 0b000);
    color_palette[1] = COLOR(0b110, 0b110, 0b110);
    color_palette[2] = COLOR(0b100, 0b100, 0b100);
    color_palette[3] = COLOR(0b111, 0b111, 0b111);
    memcpy(front_buffer, cpu_timeout, SCREEN_BUFFER_SIZE);
}

void dma1_channel2_isr(void) {
    dma_clear_interrupt_flags(DMA1, DMA_CHANNEL2, DMA_ISR_TCIF_BIT);
    dma_disable_channel(DMA1, DMA_CHANNEL2);
    switch (processing_stage) {
    case UNINITIALIZED:
        if (OPERATION_ID(operation) != OPERATION_ID_INIT) {
            // 1. Operation was not the sync operation...
            // The communication is not reliable and should not be
            // trusted with further operations. An error will be
            // displayed automatically via the systick interupt.
            run = false;
            break;
        }
    case READY:
        processing_stage = UNHANDELED_OPERATION;
        break;
    case WAITING_FOR_DATA:
        processing_stage = UNHANDELED_DATA;
        break;
    case WAITING_FOR_DMA:
        processing_stage = READY;
        dma_recieve_operation();
        GPIO_BSRR(GPU_READY_PORT) = GPU_READY;
        gpu_ready_port = GPU_READY;
        break;
    default:
        unexpected_data(processing_stage);
        break;
    }
}

void handle_operation(void) {
    switch (processing_stage) {
    case UNHANDELED_OPERATION:
        new_operation();
        break;
    case UNHANDELED_DATA:
        new_data();
        break;
    default:
        break;
    }
}

void new_operation(void) {
    gpu_ready_port = 0;
    GPIO_BRR(GPU_READY_PORT) = GPU_READY;
    if (INTERNAL_OPERATION(operation)) {

        switch (OPERATION_ID(operation)) {
        case INTERNAL_SHOW_STARTUP:
            memcpy(front_buffer, splash_screen, SCREEN_BUFFER_SIZE);
            uint8_t su_colors[4][3] = {
                {0b000, 0b000, 0b000},
                {0b111, 0b001, 0b001},
                {0b101, 0b101, 0b101},
                {0b111, 0b111, 0b111},
            };

            // set the inital palette
            for (uint8_t i = 0; i < 4; ++i)
                color_palette[i] =
                    COLOR(su_colors[i][0], su_colors[i][1], su_colors[i][2]);

            gpu_write(front_buffer, 15, 100, 0, 3, "GITHUB.COM/MENGA-TEAM");
            // not going to start a timer just for that...
            for (uint32_t i = 0; i < 5000000; ++i)
                __asm__("nop");

            // fade out
            while (su_colors[3][0] != 0) { // [3] is white
                for (uint8_t i = 0; i < 4; ++i) {
                    for (uint8_t j = 0; j < 3; ++j) {
                        if (su_colors[i][j] != 0)
                            su_colors[i][j]--;
                    }
                    color_palette[i] = COLOR(su_colors[i][0], su_colors[i][1],
                                             su_colors[i][2]);
                }
                for (uint32_t i = 0; i < 200000; ++i)
                    __asm__("nop");
            }
            gpu_blank(front_buffer, 0x00);
            gpu_reset_palette();
            break;
        case INTERNAL_ADJUST_BRIGHTNESS:
            memcpy(front_buffer, adjust_brightness, SCREEN_BUFFER_SIZE);
            uint8_t ab_colors[8][3] = {
                {0b000, 0b000, 0b000}, {0b110, 0b110, 0b110},
                {0b101, 0b101, 0b101}, {0b111, 0b111, 0b111},
                {0b100, 0b100, 0b100}, {0b011, 0b011, 0b011},
                {0b010, 0b010, 0b010}, {0b001, 0b001, 0b001},
            };

            // set the inital palette
            for (uint8_t i = 0; i < 8; ++i)
                color_palette[i] =
                    COLOR(ab_colors[i][0], ab_colors[i][1], ab_colors[i][2]);

            gpu_write(front_buffer, 10, 42, 3, 0, " PLEASE ADJUST YOUR     ");
            gpu_write(front_buffer, 10, 50, 3, 0, " MONITOR OR TELEVISION  ");
            gpu_write(front_buffer, 10, 58, 3, 0, " BRIGHTNESS SETTINGS    ");
            gpu_write(front_buffer, 10, 66, 3, 0, " IF YOU CAN'T SEE       ");
            gpu_write(front_buffer, 10, 74, 3, 0, " 7 DISTINCT SQUARES     ");

            gpu_write(front_buffer, 10, 90, 3, 0, " PLEASE PLAY IN A       ");
            gpu_write(front_buffer, 10, 98, 3, 0, " WELL-LIT AREA          ");
            gpu_write(front_buffer, 10, 106, 3, 0, " FROM A SAFE DISTANCE   ");

            for (uint32_t i = 0; i < 15000000; ++i)
                __asm__("nop");

            // fade out
            while (ab_colors[3][0] != 0) { // [3] is white
                for (uint8_t i = 0; i < 8; ++i) {
                    for (uint8_t j = 0; j < 3; ++j) {
                        if (ab_colors[i][j] != 0)
                            ab_colors[i][j]--;
                    }
                    color_palette[i] = COLOR(ab_colors[i][0], ab_colors[i][1],
                                             ab_colors[i][2]);
                }
                for (uint32_t i = 0; i < 300000; ++i)
                    __asm__("nop");
            }
            gpu_blank(front_buffer, 0x00);
            gpu_reset_palette();
            break;
        case INTERNAL_DRAW_SDCARD:
            gpu_insert_buf(OPERATION_BUFFER(operation), sdcard, SDCARD_WIDTH,
                           SDCARD_HEIGHT, operation[6], operation[7]);
            break;
        case INTERNAL_DRAW_CONTROLLER: {
            const uint8_t *texture;
            switch (operation[4]) {
            case 0:
                texture = controller1;
                break;
            case 1:
                texture = controller2;
                break;
            case 2:
                texture = controller3;
                break;
            case 3:
                texture = controller4;
                break;
            default:
                texture = controller1;
            }
            const uint8_t width = 16, height = 16;
            uint8_t x = operation[6], y = operation[7];
            for (uint8_t c_x = 0; c_x < width; ++c_x) {
                for (uint8_t c_y = 0; c_y < height; ++c_y) {
                    uint8_t pixel = gpu_get_pixel(texture, c_y * width + c_x);
                    if (pixel == 1) {
                        pixel = operation[5];
                    } else {
			pixel = operation[1];
		    }
                    gpu_set_pixel(OPERATION_BUFFER(operation),
                                  (y + c_y) * BUFFER_WIDTH + x + c_x, pixel);
                }
            }
        } break;
        default:
            invalid_operation(operation);
            break;
        }

        dma_recieve_operation();
        processing_stage = READY;
        gpu_ready_port = GPU_READY;
        return;
    }
    switch (OPERATION_ID(operation)) {
    case OPERATION_ID_INIT:
        gpu_write(front_buffer, 0, 0, 1, 0, "GPU INITIALIZED");
        dma_recieve_operation();
        processing_stage = READY;
        break;
    case OPERATION_ID_SWAP_BUF:
        gpu_swap_buffers();
        dma_recieve_operation();
        processing_stage = READY;
        break;
    case OPERATION_ID_DISPLAY_BUF:
    case OPERATION_ID_SEND_BUF:
        if (operation[4] == 0x00 && operation[5] == 0x00 &&
            operation[6] == 0x00 && operation[7] == 0x00) {
            if (OPERATION_ID(operation) ==
                OPERATION_ID_DISPLAY_BUF) { // TODO: stupid hack...
                operation[2] = 0x01;
            }
            // recieve full frame via dma
            dma_recieve((uint32_t)OPERATION_BUFFER(operation),
                        SCREEN_BUFFER_SIZE);
            processing_stage = WAITING_FOR_DMA;
        } else {
            uint16_t buffer_size = BUFFER_SIZE(operation[6], operation[7]);
            if (buffer_size > OPERATION_DATA_LENGTH) {
                too_large_data(buffer_size);
                return;
            }
            dma_recieve((uint32_t)operation_data, buffer_size);
            processing_stage = WAITING_FOR_DATA;
        }
        GPIO_BSRR(GPU_READY_PORT) = GPU_READY;
        return;
    case OPERATION_ID_PRINT_TEXT:
        dma_recieve((uint32_t)operation_data, operation[5]);
        processing_stage = WAITING_FOR_DATA;
        break;
    case OPERATION_ID_CHANGE_PALETTE:
        dma_recieve((uint32_t)color_palette, sizeof(color_palette));
        processing_stage = WAITING_FOR_DMA;
        break;
    case OPERATION_ID_RESET:
        gpu_reset();
        // won't be executed. vvvv
        dma_recieve_operation();
        processing_stage = READY;
        break;
    case OPERATION_ID_BLANK:
        gpu_blank(OPERATION_BUFFER(operation), operation[7]);
        dma_recieve_operation();
        processing_stage = READY;
        break;
    default: // unimplemented operation
        invalid_operation(operation);
        processing_stage = READY;
        break;
    }
    gpu_ready_port = GPU_READY;
}

void new_data(void) {
    gpu_ready_port = 0;
    GPIO_BRR(GPU_READY_PORT) = GPU_READY;
    switch (OPERATION_ID(operation)) {
    case OPERATION_ID_DISPLAY_BUF:
    case OPERATION_ID_SEND_BUF: {
        const uint8_t x = operation[4];
        const uint8_t y = operation[5];
        const uint8_t width = operation[6];
        const uint8_t height = operation[7];
        gpu_insert_buf(OPERATION_BUFFER(operation), operation_data, width,
                       height, x, y);
        if (OPERATION_ID(operation) == OPERATION_ID_DISPLAY_BUF) {
            gpu_swap_buffers();
        }
        break;
    }
    case OPERATION_ID_PRINT_TEXT:
        gpu_write(OPERATION_BUFFER(operation), operation[6], operation[7],
                  operation[0], operation[1], (char *)operation_data);
        break;
    }
    dma_recieve_operation();
    processing_stage = READY;
    gpu_ready_port = GPU_READY;
}

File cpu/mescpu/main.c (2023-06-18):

/* This file is part of MES.
 *
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
 * You should have received a copy of the GNU General Public License
 * along with MES. If not, see <https://www.gnu.org/licenses/>.
 */

#include "gpu.h"
#include "gpu_internal.h"
#include "input.h"
#include "input_internal.h"
#include "mes.h"
#include "mesgraphics.h"
#include "rng.h"
#include "sdcard.h"
#include "timer.h"
#include "udynlink.h"
#include <libopencm3/cm3/nvic.h>
#include <libopencm3/stm32/flash.h>
#include <libopencm3/stm32/gpio.h>
#include <libopencm3/stm32/rcc.h>
#include <malloc.h>
#include <math.h>
#include <memory.h>
#include <stddef.h>
#include <stdint.h>
#include <stdio.h>

uint32_t __attribute__((section(".get_lot_base"))) (*const get_lot_base)(
    uint32_t) = &udynlink_get_lot_base;

const char *GAME_ENTRY = "start";

const uint32_t REVISION =
#include "../../REVISION"
    ;

// Used for testing a game without flashing a sdcard.
#include "dummy_game.h"

uint8_t run_game(void *adr) {
    gpu_print_text(FRONT_BUFFER, 0, 0, 1, 0, "LOADING GAME...");
    udynlink_module_t *p_game;
    udynlink_error_t p_error;
    p_game =
        udynlink_load_module(adr, NULL, 0, UDYNLINK_LOAD_MODE_XIP, &p_error);
    if (p_error != UDYNLINK_OK) {
        gpu_print_text(FRONT_BUFFER, 0, 8, 2, 0, "ERROR LOADING GAME:");
        gpu_print_text(FRONT_BUFFER, 0, 16, 1, 0, error_codes[p_error]);
        if (p_error == UDYNLINK_ERR_LOAD_UNKNOWN_SYMBOL) {
            gpu_print_text(FRONT_BUFFER, 0, 24, 1, 0, unknown_symbol);
        }
        return -1;
    }

    gpu_print_text(FRONT_BUFFER, 0, 8, 1, 0, "STARTING GAME...");
    udynlink_sym_t sym;
    if (udynlink_lookup_symbol(p_game, GAME_ENTRY, &sym) != NULL) {
        uint8_t (*p_main)(void) = (uint8_t(*)(void))sym.val;
        return p_main();
    } else {
        gpu_print_text(FRONT_BUFFER, 0, 8, 2, 0, "UNABLE TO FIND ENTRYPOINT:");
        gpu_print_text(FRONT_BUFFER, 0, 16, 1, 0, GAME_ENTRY);
        return -1;
    }
    udynlink_unload_module(p_game);
}

static void startup_animation(void) {
    uint32_t block_until = timer_get_ms() + 1000;
    while (timer_get_ms() < block_until) {
        if (input_get_button(CONTROLLER_1, BUTTON_A)) {
            return;
        }
    }
    gpu_block_frame();
    gpu_show_startup();
    gpu_block_frame();
    block_until = timer_get_ms() + 1000;
    while (timer_get_ms() < block_until) {
        if (input_get_button(CONTROLLER_1, BUTTON_A)) {
            return;
        }
    }
    gpu_block_frame();
    gpu_adjust_brightness();
    gpu_block_frame();
    block_until = timer_get_ms() + 500;
    while (timer_get_ms() < block_until) {
        if (input_get_button(CONTROLLER_1, BUTTON_A)) {
            return;
        }
    }
    gpu_block_frame();
}

static void check_controller(uint8_t controller) {
    gpu_blank(FRONT_BUFFER, 0);
    gpu_reset_palette();
    char *text = (char *)malloc(29);
    uint8_t fg;

    gpu_print_text(FRONT_BUFFER, 0, 112, 1, 0,
                   "PRESS " FONT_BUTTONA "+" FONT_BUTTONB " TO RETURN.");

    while (true) {
        volatile bool *buttons = input_get_buttons(controller);
        if (input_is_available(controller)) {
            sprintf(text, "CONTROLLER%i IS CONNECTED  ", controller + 1);
            fg = 3;
        } else {
            sprintf(text, "CONTROLLER%i IS DISCONNETED", controller + 1);
            fg = 2;
        }
        gpu_print_text(FRONT_BUFFER, 0, 8, fg, 0, text);
        gpu_block_ack();
        gpu_block_frame();
        for (uint8_t i = 0; i < 8; ++i) {
            if (buttons[i]) {
                sprintf(text, "%-3s PRESSED ", BUTTON_CHARACTERS[i]);
                fg = 3;
            } else {
                sprintf(text, "%-3s RELEASED", BUTTON_CHARACTERS[i]);
                fg = 2;
            }
            gpu_print_text(FRONT_BUFFER, 0, (i + 2) * 8, fg, 0, text);
            gpu_block_ack();
        }
        for (uint8_t i = 0; i < 4; ++i) {
            if (input_get_button(i, BUTTON_A) &&
                input_get_button(i, BUTTON_B)) {
                return;
            }
        }
    }
    free(text);
}

static void copy_game(uint8_t sectors) {
    if (SD_SECTOR_SIZE * 2 != FLASH_PAGE_SIZE) {
        error_with_message("calc", "");
    }

    flash_unlock();
    uint8_t *data = malloc(SD_SECTOR_SIZE * 2);
    uint32_t page_adr = FLASH_GAME_ADR;
    uint32_t flash_status = 0;
    for (uint32_t i = 0; i < sectors; i += 2) {
        // read from sd
        sdcard_read_sector(1 + i, data);
        sdcard_read_sector(2 + i, data + SD_SECTOR_SIZE);

        if ((FLASH_GAME_ADR - FLASH_BASE) >=
            (FLASH_PAGE_SIZE * (FLASH_PAGE_NUM_MAX + 1))) {
            error_with_message("out of bounds", "");
        }

        flash_erase_page(page_adr);
        flash_status = flash_get_status_flags();
        if (flash_status != FLASH_SR_EOP) {
            error_with_message("sr eop", "");
        }

        for (uint32_t word = 0; word < SD_SECTOR_SIZE * 2; word += 4) {
            flash_program_word(page_adr + word, *((uint32_t *)(data + word)));
            if (*((uint32_t *)(page_adr + word)) !=
                *((uint32_t *)(data + word))) {
                error_with_message("integrity failure", "");
            }
        }
        page_adr += FLASH_PAGE_SIZE;
    }
    free(data);
    flash_lock();
}
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

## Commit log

2022-10-05 inbuilt-led test
2022-10-06 bug in video buffer (and maybe tim3?)
    [main.c]
2022-10-08 fix buffer + improve performance
    [gpu.h, main.c]
2022-10-08 trying out various techniques for getting pixel sizes correct
    [main.c]
2022-10-10 eagle setup
    [controller.brd, controller.sch]
2022-10-14 acceptable ig 🤷
2022-10-14 controller board with eagle
    [controller.brd, controller.sch]
2022-10-19 usb type b
    [controller.sch]
2022-10-21 create mainboard scematic
    [mainboard.sch]
2022-10-23 add usb type c
    [controller.sch, mainboard.sch]
2022-10-29 fix scanline size & various improvments
    [gpu.h, main.c, main.rs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]
2022-11-22 implemented function in wrong file
    [main.c, sdcard.c]
2022-11-23 added mainboard controller logic
    [mainboard.sch]
2022-11-25 mainboard controller schematic
    [mainboard.sch]
2022-11-26 send gpu data via dma instead of blocking
2022-12-01 replaced usb-c 24 pin reciver with 12 pin reciver
    [mainboard.sch]
2022-12-17 pyqt5 script to emulate a controller using an arduino (UNO)
2022-12-23 2nd reset before giving up if first failed
    [sdcard.c, sdcard.h]
2022-12-24 deleted vga.sch and updated eagle library
    [vga.sch]
2023-01-18 updated USB-C receptacles and würth library
    [mainboard.sch]
2023-01-18 renamed the pins for CPU and GPU
    [mainboard.sch]
2023-01-18 update games to reflect changes in timer module
2023-01-18 cleaned up schemtic
    [mainboard.sch]
2023-01-18 added Board to board connector
    [mainboard.sch]
2023-01-18 add function for swapping buffers
    [gpu.c, gpu.h, main.c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]
2023-01-18 free allocated buffers when error occurs
    [main.c]
2023-01-20 fixed schematic
    [controller.sch, mainboard.sch]
2023-01-22 new controller logic implemented
    [controller.sch, mainboard.sch]
2023-01-22 erc check
    [controller.sch, mainboard.sch]
2023-01-23 fixed controller.sch
    [controller.sch]
2023-01-25 changed usb-c pin used by controller
    [controller.sch, mainboard.sch]
2023-01-25 changed connector library ad wired up to cpu/gpu
    [mainboard.sch]
2023-01-25 wired sd card slot
    [gpu.sch, mainboard.sch]
2023-01-27 finalized schematik with detommaso and spiss supervision
    [controller.sch, mainboard.sch]
2023-02-12 reimplement gpu ready & switch to 640x480@60
2023-02-13 Schematic V1
    [controller.sch, gpu.sch, mainboard.sch]
2023-02-15 Schematic complete
    [mainboard.sch]
2023-02-24 fixing local symbols in multiple files when compiling module.
    Reformat everything with the new style
    [controller_internal.h, gpu.c, gpu.h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]
2023-03-14 Board almost finished
    [mainboard.brd, mainboard.sch]
2023-03-18 fix image cut off edge case
    [main.rs]
2023-03-18 set board labels and fixed errors
    [mainboard.brd, mainboard.sch]
2023-03-18 implement flashing with game, and fix fpn.
    [main.c]
2023-03-19 added fancy drawings and logos on the back of the board
    [mainboard.brd]
2023-03-19 some drc improvements
    [mainboard.brd]
2023-03-19 fixed errors, rewired controller clock and fixed buttons on wrong layer
    [mainboard.brd]
2023-03-20 huber approve check has been given
    [mainboard.brd]
2023-03-20 usb change
    [mainboard.brd, mainboard.sch]
2023-03-21 board changes
    [mainboard.brd]
2023-03-21 positioned controller reciver, massive cleanup, simplified routes, moved labels
    [mainboard.brd, mainboard.sch]
2023-04-13 use error messages from udynlink
    [main.c]
2023-04-13 print unknown symbol
2023-04-14 Work in progress board rework
    [mainboard.brd, mainboard.sch]
2023-04-15 update software to match board
2023-04-15 reset palette when reconnecting
    [gpu.c, gpu.h, main.c]
2023-04-21 pcb v2
2023-04-21 pcb: gpu ready led
    [mainboard.brd, mainboard.sch]
2023-04-26 made D-pad quadrtatic, corrected other minor stuff
    [mainboard.brd, mainboard.sch]
2023-04-27 added svg art and finished todo list
    [mainboard.brd, mainboard.sch]
2023-04-28 fix all warnings when compiling cpu
    [main.c]
2023-05-03 pcb: v2 features
    [mainboard.brd, mainboard.sch]
2023-05-03 huber approved pcb 2.0
    [mainboard.brd, mainboard.sch]
2023-05-07 fix small memory leaks
    [main.c, main.rs]
2023-05-07 run flashed game if cpu was reset and gpu is already initialized.
    [main.c]
2024-04-04 sdcard: Fix the CRC16 algorithm.
    [sdcard.c]

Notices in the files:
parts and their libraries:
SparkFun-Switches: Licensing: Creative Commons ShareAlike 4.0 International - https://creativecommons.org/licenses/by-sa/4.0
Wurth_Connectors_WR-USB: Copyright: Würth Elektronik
